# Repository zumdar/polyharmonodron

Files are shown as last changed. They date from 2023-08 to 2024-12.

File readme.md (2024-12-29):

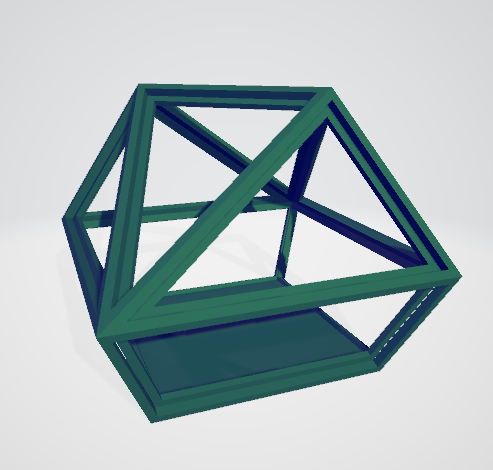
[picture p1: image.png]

# polyharmonodron


a toy for my neice's 2nd birthday!

its an 11 sided polyhedron

its has 9 buttons and 2 speakers

## Update 12.29.2024
now includes a special mode where if you input the correct sequence, it plays a special sound and rainbow lighting sequence!

# credits


Special thank you to Jason Coombs for modeling the 11 sided object and making the .blend file. 

Special thank you to Peter Chu for taking the model into Fusion and making this wireframe so I could 3d print it and put the laser cut acrylic in it. 



# pinout


## buttons

 button0 = pin 0 <br>
 button1 = pin 1 <br>
 button2 = pin 2<br>
 button3 = pin 3<br>
 button4 = pin 4<br>
 button5 = pin 5<br>
 button7 = pin 10<br>
 button8 = pin 11<br>

## ws2812 (led strip) output
LED_PIN - 9 

 ## audio shield (automatic but good to remember)
 MCLK - 23<br>
 BCLK - 21<br>
 LRCLK - 20<br>
DIN (audio output) - 7

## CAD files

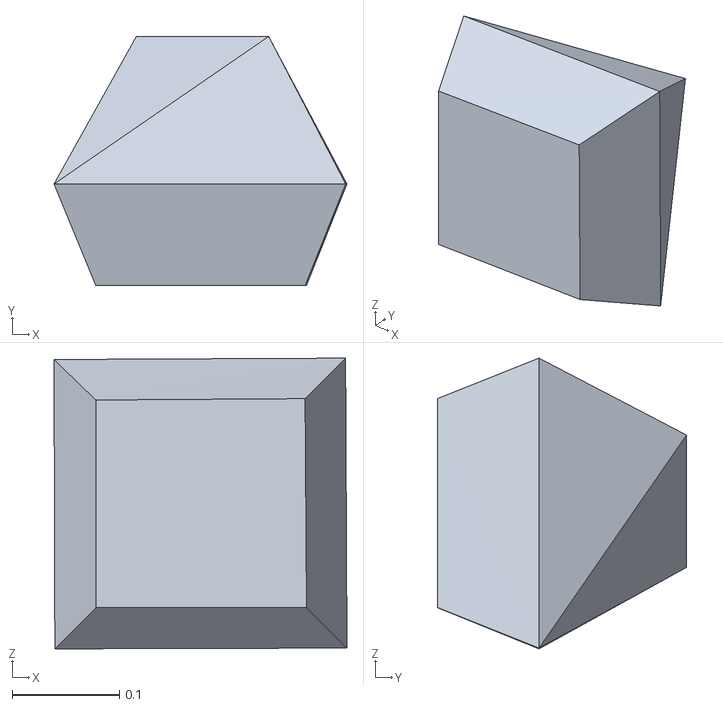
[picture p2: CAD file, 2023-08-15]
3d files for 3d printing/eleven_sided_toy_alt_001.obj
0.274 x 0.233 x 0.272

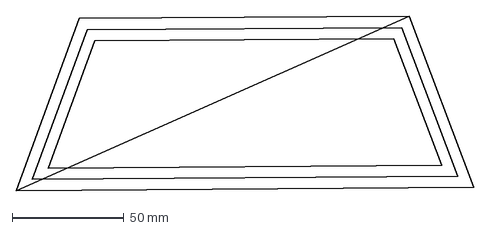
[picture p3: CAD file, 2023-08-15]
laser cuts for panels/sketch9_bottom2.dxf
204.7 x 78.0 mm

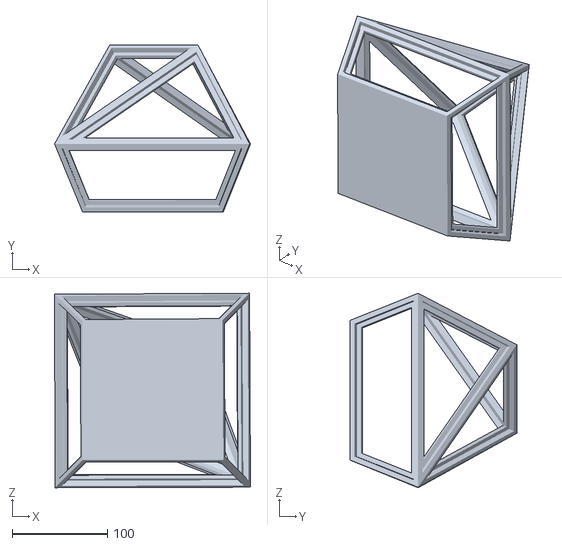
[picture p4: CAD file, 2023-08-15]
3d files for 3d printing/eleven_sided_toy v4.stl
205.3 x 174.5 x 203.8

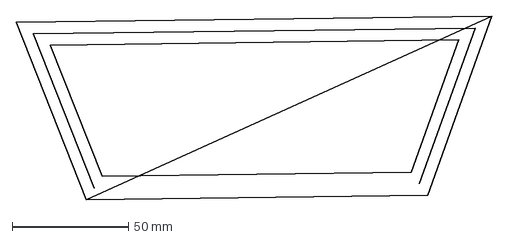
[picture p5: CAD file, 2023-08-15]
laser cuts for panels/sketch6_bottom4.dxf
204.3 x 78.9 mm

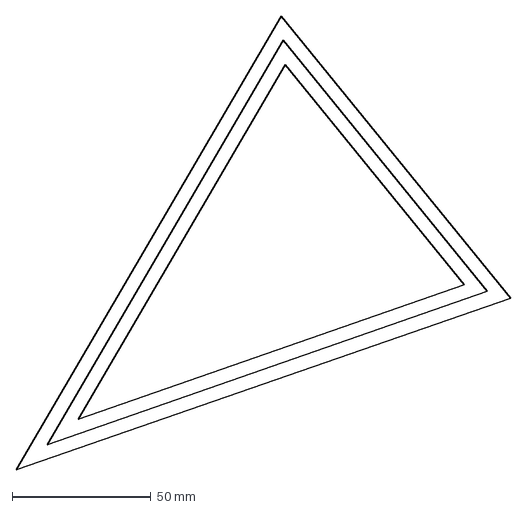
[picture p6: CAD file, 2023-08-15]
laser cuts for panels/sketch18.dxf
178.4 x 163.8 mm

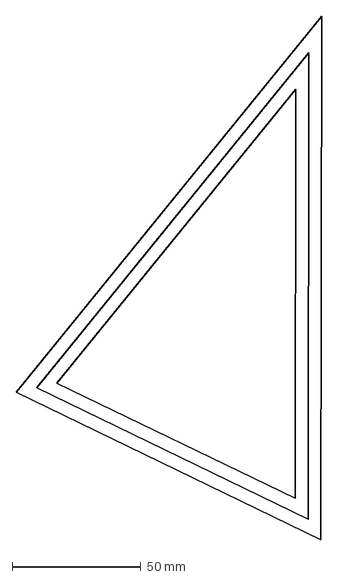
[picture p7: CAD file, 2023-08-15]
laser cuts for panels/sktch16.dxf
118.4 x 202.8 mm

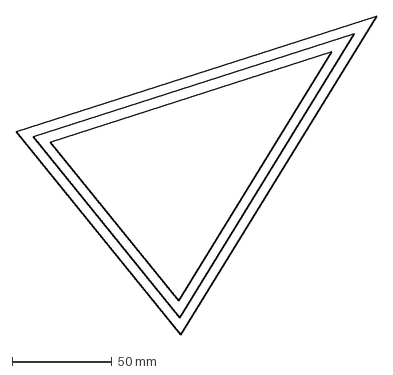
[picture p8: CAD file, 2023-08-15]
laser cuts for panels/sketch15.dxf
180.9 x 159.9 mm

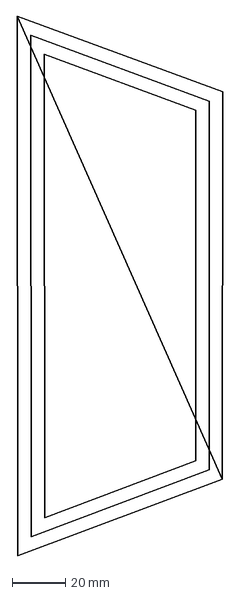
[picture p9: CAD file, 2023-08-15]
laser cuts for panels/sketch10_bottom1.dxf
77.1 x 202.8 mm

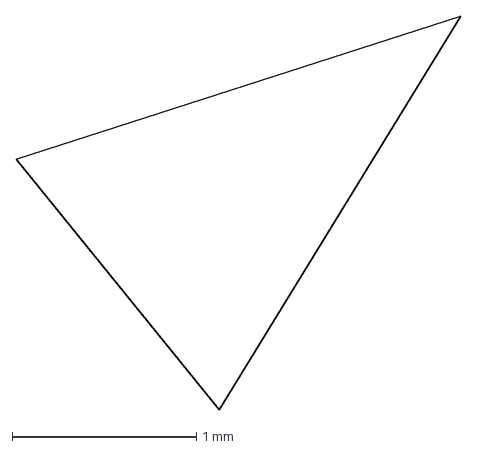
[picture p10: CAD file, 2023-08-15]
laser cuts for panels/sketch1.dxf
2.41 x 2.13 mm

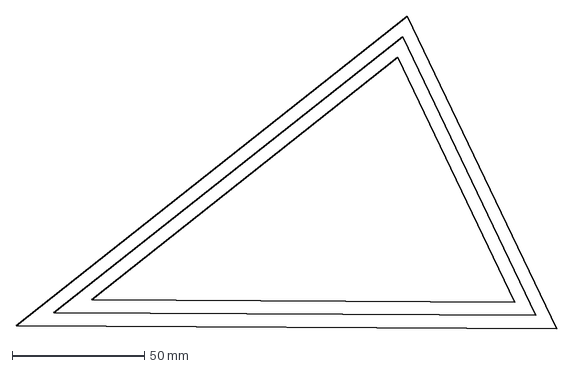
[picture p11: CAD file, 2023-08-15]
laser cuts for panels/sketch17.dxf
204.7 x 118.4 mm

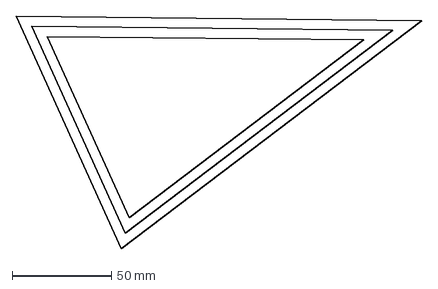
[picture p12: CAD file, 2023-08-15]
laser cuts for panels/sketch14.dxf
204.3 x 117.0 mm

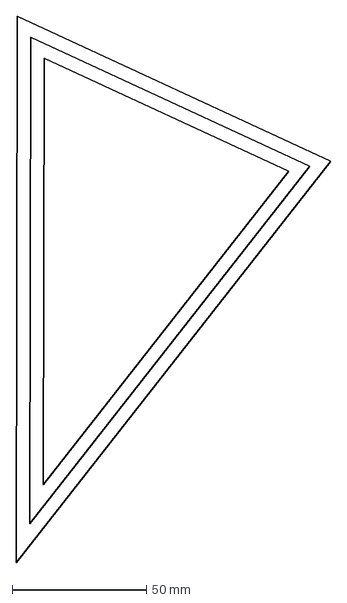
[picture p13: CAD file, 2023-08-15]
laser cuts for panels/sketch13.dxf
117.0 x 203.2 mm

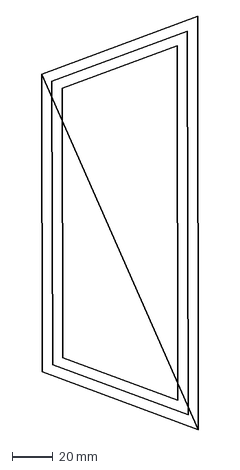
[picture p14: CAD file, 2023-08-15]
laser cuts for panels/sketch8_bottom3.dxf
76.9 x 203.2 mm

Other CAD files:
3d files for 3d printing/eleven_sided_toyV1.3mf
3d files for 3d printing/eleven_sided_toy v4.f3d
3d files for 3d printing/eleven_sided_toy_001.blend
3d files for 3d printing/eleven_sided_toy_alt_001.blend

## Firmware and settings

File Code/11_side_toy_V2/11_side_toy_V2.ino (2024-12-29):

/// CODE for an 11 sided toy for June's 2nd birthday, August 25, 2023
//// first pass, 8.14.23
// update 12.29.2024 V2
// 450MhZ works
/// william kennedy
#include <Audio.h>
#include <Wire.h>
#include <SPI.h>
#include <SD.h>
#include <SerialFlash.h>
#include <Bounce.h>
#include <FastLED.h>
#include <Snooze.h>


// Version Info to be displayed when opening serial port
String versionInfo = "POLYHARMONODRON - 12/29/2024 V2 code update. https://github.com/zumdar/polyharmonodron";
bool serialOpened = false;

// Sequence Functionality
int correctSeq[] = { 1, 5, 3 };  // The correct button sequence DONT USE 2, that is the clear button
const int arraySize = sizeof(correctSeq) / sizeof(correctSeq[0]);
int enteredSeq[arraySize];  // Store entered sequence
int currentCount = 0;
int startIndex = 0;
bool arrayAreEqual = false;

// Sleep / Snooze functionality // NOT IMPLEMENTED YET 12/29/2024
int timeout = 180000;
SnoozeTimer timer;
SnoozeDigital digital;
SnoozeBlock config(timer, digital);
unsigned long lastActivityTime = 0;


// GUItool: begin automatically generated code
AudioPlaySdWav sound0;  //xy=142,116
AudioPlaySdWav sound1;  //xy=158,190
AudioPlaySdWav sound2;  //xy=172,252
AudioPlaySdWav sound3;  //xy=208,308
AudioPlaySdWav sound4;  //xy=218.1999969482422,368.1999816894531
AudioPlaySdWav sound5;  //xy=229.1999969482422,422.1999816894531
AudioPlaySdWav sound6;  //xy=238.1999969482422,475.1999816894531
AudioPlaySdWav sound7;  //xy=247.1999969482422,518.2000122070312
AudioPlaySdWav sound8;  //xy=248.1999969482422,559.2000122070312
AudioMixer4 mixL1;      //xy=414.99999237060547,140.00000190734863
AudioMixer4 mixR1;      //xy=423.1999740600586,317.1999702453613
AudioMixer4 mixL2;      //xy=448.1999816894531,411.1999816894531
AudioMixer4 mixR2;      //xy=463.1999816894531,530.2000122070312
AudioMixer4 mixL3;      //xy=597.2000350952148,243.19998741149902
AudioMixer4 mixR3;      //xy=623.2001609802246,396.1999740600586
AudioOutputI2S i2s1;    //xy=790.0000267028809,274.99997329711914
AudioConnection patchCord1(sound0, 0, mixL1, 0);
AudioConnection patchCord2(sound0, 1, mixR1, 0);
AudioConnection patchCord3(sound1, 0, mixL1, 1);
AudioConnection patchCord4(sound1, 1, mixR1, 1);
AudioConnection patchCord5(sound2, 0, mixL1, 2);
AudioConnection patchCord6(sound2, 1, mixR1, 2);
AudioConnection patchCord7(sound3, 0, mixL1, 3);
AudioConnection patchCord8(sound3, 1, mixR1, 3);
AudioConnection patchCord9(sound4, 0, mixL2, 0);
AudioConnection patchCord10(sound4, 1, mixR2, 0);
AudioConnection patchCord11(sound5, 0, mixL2, 1);
AudioConnection patchCord12(sound5, 1, mixR2, 1);
AudioConnection patchCord13(sound6, 0, mixL2, 2);
AudioConnection patchCord14(sound6, 1, mixR2, 2);
AudioConnection patchCord15(sound7, 0, mixL2, 3);
AudioConnection patchCord16(sound7, 1, mixR2, 3);
AudioConnection patchCord17(sound8, 0, mixL3, 2);
AudioConnection patchCord18(sound8, 1, mixR3, 2);
AudioConnection patchCord19(mixL1, 0, mixL3, 0);
AudioConnection patchCord20(mixR1, 0, mixR3, 0);
AudioConnection patchCord21(mixL2, 0, mixL3, 1);
AudioConnection patchCord22(mixR2, 0, mixR3, 1);
AudioConnection patchCord23(mixL3, 0, i2s1, 0);
AudioConnection patchCord24(mixR3, 0, i2s1, 1);
// GUItool: end automatically generated code

#define SDCARD_CS_PIN 10
#define SDCARD_MOSI_PIN 7
#define SDCARD_SCK_PIN 14

/// LED SETUP //////
#define NUM_LEDS 60  // Change this to the number of LEDs in your strip
#define LED_PIN 9    // Change this to the data pin for your LED strip
CRGB leds[NUM_LEDS];
#define SEGMENT_SIZE 10  // Size of each color segment

// Create an object to control the audio shield.
AudioControlSGTL5000 audioShield;

// BUTTONS
// Bounce objects to read eight pushbuttons (pins 0-6, and pin 10)
const int NUM_BUTTONS = 8;
Bounce button0 = Bounce(0, 5);
Bounce button1 = Bounce(1, 5);  // 5 ms debounce time
Bounce button2 = Bounce(2, 5);
Bounce button3 = Bounce(3, 5);
Bounce button4 = Bounce(4, 5);
Bounce button5 = Bounce(5, 5);
Bounce button6 = Bounce(6, 5);
Bounce button7 = Bounce(10, 5);

void setup() {
  // Configure the pushbutton pins for pullups.
  // Each button should connect from the pin to GND.
  for (int i = 0; i < 7; i++) {
    pinMode(i, INPUT_PULLUP);
  }
  pinMode(10, INPUT_PULLUP);
  pinMode(13, OUTPUT);
  digitalWrite(13, HIGH);  // TURN on led so we know the thing is on

  // Initialize FastLED
  FastLED.addLeds<WS2812B, LED_PIN, GRB>(leds, NUM_LEDS);
  FastLED.setBrightness(50);                // Set the initial brightness
  fill_solid(leds, NUM_LEDS, CRGB::Black);  // Turn off all LEDs
  FastLED.show();

  // Audio connections require memory to work.  For more
  // detailed information, see the MemoryAndCpuUsage example
  AudioMemory(10);

  // turn on the output
  audioShield.enable();
  audioShield.volume(0.8);

  SPI.setMOSI(SDCARD_MOSI_PIN);
  SPI.setSCK(SDCARD_SCK_PIN);
  if (!(SD.begin(SDCARD_CS_PIN))) {
    // stop here, but print a message repetitively
    while (1) {
      Serial.println("Unable to access the SD card");
      delay(500);
    }
  }

  // by default the Teensy 3.1 DAC uses 3.3Vp-p output
  // if your 3.3V power has noise, switching to the
  // internal 1.2V reference can give you a clean signal
  //dac.analogReference(INTERNAL);

  // reduce the gain on mixer channels, so more than 1
  // sound can play simultaneously without clipping
  mixL1.gain(0, 0.4);
  mixL1.gain(1, 0.4);
  mixL1.gain(2, 0.4);
  mixL1.gain(3, 0.4);
  mixR1.gain(0, 0.4);
  mixR1.gain(1, 0.4);
  mixR1.gain(2, 0.4);
  mixR1.gain(3, 0.4);
  mixL2.gain(0, 0.4);
  mixL2.gain(1, 0.4);
  mixL2.gain(2, 0.4);
  mixL2.gain(3, 0.4);
  mixR2.gain(0, 0.4);
  mixR2.gain(1, 0.4);
  mixR2.gain(2, 0.4);
  mixR2.gain(3, 0.4);
  mixL3.gain(0, 0.4);
  mixL3.gain(1, 0.4);
  mixL3.gain(2, 0.4);
  mixR3.gain(0, 0.4);
  mixR3.gain(1, 0.4);
  mixR3.gain(2, 0.4);
}

void loop() {
  // VERSION INFO
  // (so easy to find out what is on there when it comes time to update)
  if (Serial && !serialOpened) {
    Serial.println(versionInfo);
    serialOpened = true;
  }
  if (!Serial) { serialOpened = false; }
  // SLEEP STUFF
  if (millis() - lastActivityTime > timeout) {  // 3 minutes in milliseconds
    FastLED.clear();
    FastLED.show();
    // Snooze.deepSleep(config);
    // Code here will run after waking up
    // lastActivityTime = millis();  // Reset activity timer
  }

  // Update all the button objects
  button0.update();
  button1.update();
  button2.update();
  button3.update();
  button4.update();
  button5.update();
  button6.update();
  button7.update();

  // When the buttons are pressed, start a sound playing.
  // sounds can be played simultaneously
  if (button0.risingEdge()) {
    lastActivityTime = millis();
    enteredSeq[currentCount] = 0;
    currentCount = (currentCount + 1) % arraySize;
    sound0.play("BRINK.WAV");
    fill_solid(leds, NUM_LEDS, CRGB::Yellow);
  }
  if (button1.risingEdge()) {
    lastActivityTime = millis();
    enteredSeq[currentCount] = 1;
    currentCount = (currentCount + 1) % arraySize;
    fill_solid(leds, NUM_LEDS, CRGB::Red);
    sound1.play("WAHOO.WAV");
  }
  if (button2.risingEdge()) {
    // CLEAR THE ARRAY and the current count back to 0
    currentCount = 0;
    for (int i = 0; i < arraySize; i++) {
      enteredSeq[i] = 0;  //
    }
    stopAudio();
    FastLED.clear();
    sound2.play("BYE.WAV");
  }
  if (button3.risingEdge()) {
    lastActivityTime = millis();
    enteredSeq[currentCount] = 3;
    currentCount = (currentCount + 1) % arraySize;
    fill_solid(leds, NUM_LEDS, CRGB::Blue);
    sound3.play("JUNEY.WAV");
  }
  if (button4.risingEdge()) {
    lastActivityTime = millis();
    enteredSeq[currentCount] = 4;
    currentCount = (currentCount + 1) % arraySize;
    fill_solid(leds, NUM_LEDS, CRGB::White);
    sound4.play("WEE.WAV");
  }
  if (button5.risingEdge()) {
    lastActivityTime = millis();
    enteredSeq[currentCount] = 5;
    currentCount = (currentCount + 1) % arraySize;
    fill_solid(leds, NUM_LEDS, CRGB::Green);
    sound5.play("SYNTH.WAV");
  }
  if (button6.risingEdge()) {
    lastActivityTime = millis();
    enteredSeq[currentCount] = 6;
    currentCount = (currentCount + 1) % arraySize;
    fill_solid(leds, NUM_LEDS, CRGB::Cyan);
    sound6.play("HANNAH.WAV");
  }
  if (button7.risingEdge()) {
    lastActivityTime = millis();
    enteredSeq[currentCount] = 7;
    currentCount = (currentCount + 1) % arraySize;
    fill_solid(leds, NUM_LEDS, CRGB::Magenta);
    sound7.play("HELLO.WAV");
  }
  FastLED.show();
  // Serial.print("current count = ");
  // Serial.println(currentCount);
  // Serial.print("size of array  = ");
  // Serial.println(arraySize);
  // Serial.print("entered sequence is: ");
  // for (int i = 0; i < arraySize; i++) {
  //   Serial.print(enteredSeq[i]);
  // }
  // Serial.println();

  if (areArraysEqual(correctSeq, enteredSeq, arraySize) && !arrayAreEqual) {
    arrayAreEqual = true;
    stopAudio();
    startIndex = 0;
    sound8.play("GOOD_JOB_JUNE.WAV");
    rainbowChase();  // Display the rainbow gradient
    // Serial.println("Sequences match!");
  } else if (!areArraysEqual(correctSeq, enteredSeq, arraySize)) {
    // sequence doesnt match
    // Serial.println("sequences dont match!");
    arrayAreEqual = false;
  } else {
    rainbowChase();  // Display the rainbow gradient
    // Serial.println("sequences match, so in this loop, not first one");
  }
}

// HELPER FUNCTIONS
bool areArraysEqual(int arr1[], int arr2[], int size) {
  for (int i = 0; i < size; i++) {
    if (arr1[i] != arr2[i]) {
      return false;
    }
  }
  return true;
}

unsigned long lastUpdateTime = 0;
const unsigned long updateInterval = 20;  // Update every 10ms

void rainbowChase() {
  unsigned long currentTime = millis();
  if (millis() - lastActivityTime > timeout - 5000) {  // 3 minutes in milliseconds
    FastLED.clear();
    FastLED.show();

    return;
  }
  if (currentTime - lastUpdateTime >= updateInterval) {
    lastUpdateTime = currentTime;

    for (int i = 0; i < NUM_LEDS; i++) {
      int colorIndex = ((i + startIndex) / SEGMENT_SIZE) % 12;
      switch (colorIndex) {
        case 0: leds[i] = CRGB::Red; break;
        case 1: leds[i] = CRGB::Black; break;
        case 2: leds[i] = CRGB::Orange; break;
        case 3: leds[i] = CRGB::Black; break;
        case 4: leds[i] = CRGB::Yellow; break;
        case 5: leds[i] = CRGB::Black; break;
        case 6: leds[i] = CRGB::Green; break;
        case 7: leds[i] = CRGB::Black; break;
        case 8: leds[i] = CRGB::Blue; break;
        case 9: leds[i] = CRGB::Black; break;
        case 10: leds[i] = CRGB::Purple; break;
        case 11: leds[i] = CRGB::Black; break;
      }
    }
    FastLED.show();
    startIndex++;
    if (startIndex >= SEGMENT_SIZE * 12) startIndex = 0;
  }
}


void rainbowAnimation() {
  for (int i = 0; i < NUM_LEDS; i++) {
    leds[i] = CHSV(i * 255 / NUM_LEDS, 255, 255);
  }
  FastLED.show();
}

void stopAudio() {
  sound0.stop();
  sound1.stop();
  sound2.stop();
  sound3.stop();
  sound4.stop();
  sound5.stop();
  sound6.stop();
  sound7.stop();
  sound8.stop();
}

void rainbowGradient() {
  for (int i = 0; i < NUM_LEDS; i++) {
    // Calculate the color for each LED based on its position
    // This will create a smooth gradient effect
    leds[i] = CHSV((i * 255 / NUM_LEDS) + startIndex, 255, 255);
  }
  FastLED.show();
}

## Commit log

2023-08-15 readme and added 2 more buttons
2023-08-15 led pin add to readme
2023-08-23 converting wavs to work w teensy
2024-12-29 V2 released, special sequence, re did audio files, made louder, now will sleep, (lights turn off)
    [eleven_sided_toy v4.f3d, eleven_sided_toy v4.stl, eleven_sided_toyV1.3mf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]
